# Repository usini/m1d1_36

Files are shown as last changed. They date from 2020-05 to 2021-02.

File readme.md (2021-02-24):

µsini M1D1_36
-------------
An Open Source Midi controller with **36 pads** in a **compact body**.

Documentation en français : https://usini.github.io/m1d1_36/index.html

Make music on a PC or with open source sound modules.
* 36 capacitives pads  
* 4 Potentiometers    
* 10 buttons    

Based Sparkfun Pro Micro (atmega32u4)
https://www.sparkfun.com/products/12640

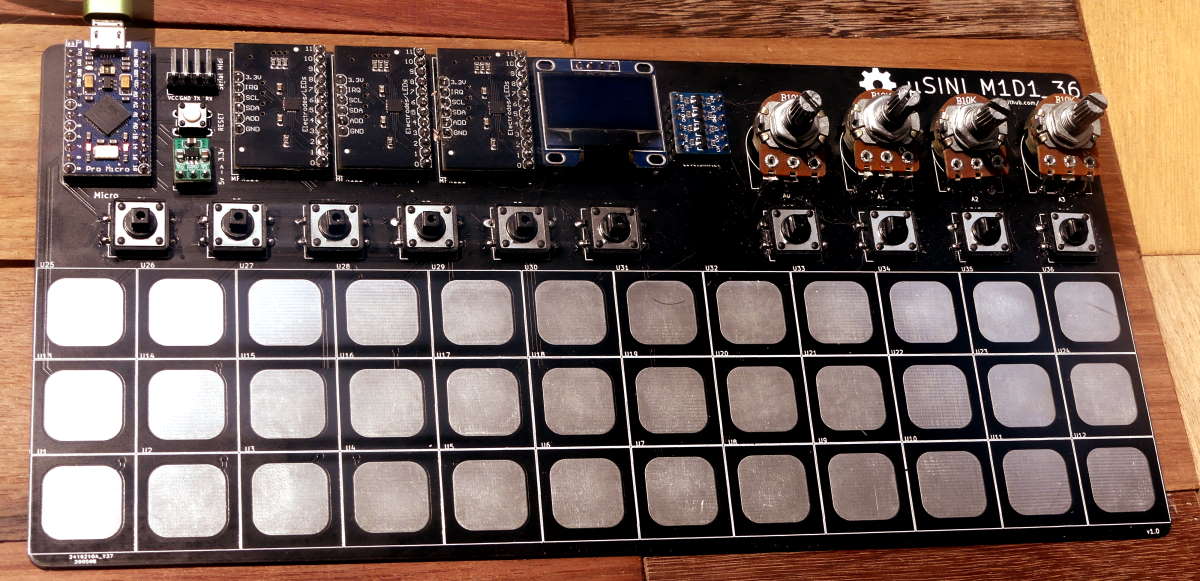
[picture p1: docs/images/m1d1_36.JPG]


# Demo

# USB Midi
Compatible with any music software   
Can also be used as a keyboard / mouse / xbox360 controller...

## Examples
LMMS - Open Source Music Software - https://lmms.io/download#windows   
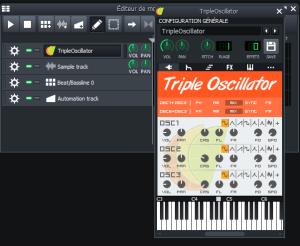
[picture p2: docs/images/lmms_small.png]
LMMS
   

PatchBox OS - Raspberry Pi synthetiser - https://blokas.io/modep/
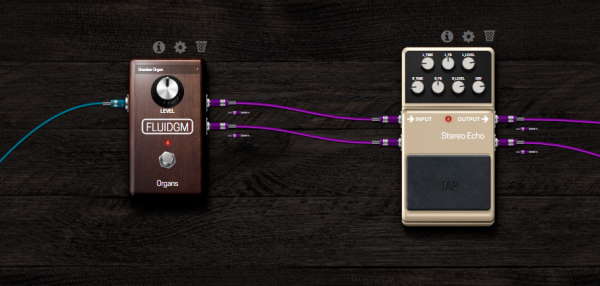
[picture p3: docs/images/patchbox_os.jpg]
PatchBox OS
 

# Serial Midi
Add controls / sound generators using open sources modules
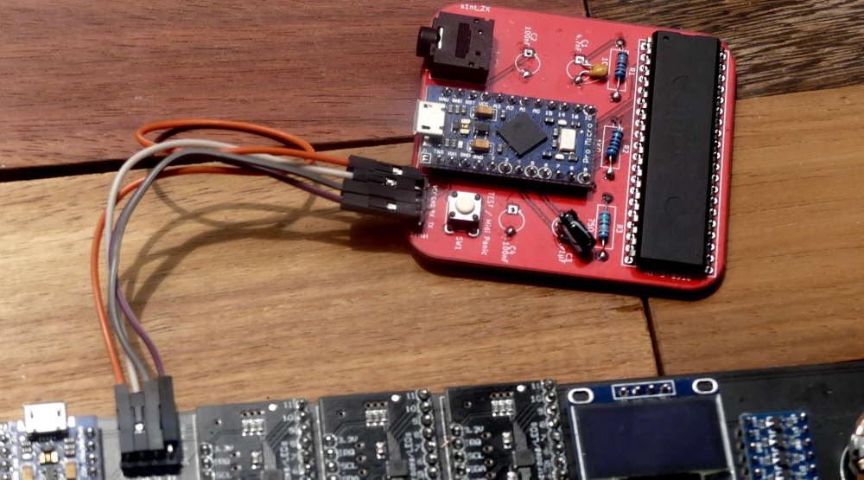
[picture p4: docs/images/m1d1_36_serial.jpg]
     
    
## Compatibles Modules
* **µsini zx** [TO BE PUBLISHED] : a AY-3-8910 sound generator (used in zx-spectrum)   
 Based on Ian Harvey design (public domain) : https://www.instructables.com/id/Arduino-MIDI-Chiptune-Synthesizer/

* **µsini opl2** [WAITING FOR COMPONENTS] : A OPL-2 FM sound generator (used in adlib sound card)   
  Based on Maarten Janssen design (MIT licence) : https://hackaday.io/project/18995-opl2-audio-board-for-arduino-raspberry-pi

* **µsini M1d1 Out** [TO MAKE] : A serial pins to Midi output
* **µsini M1d1 WiFi** [TO MAKE] : A serial midi to RtpMidi (WiFi Midi)
* **µsini M1d1 BLE** [TO MAKE] : A serial midi to BLE 

# Make your own
Fast and easy to solder as this midi controller used only modules.

## Send Gerbers to PCB Manufacturer

## Buy component
You can either choose to buy components from a chinese clone manufacturer or the original source.

### Clone links (sponsored)

### Sparkfun links

## Solder it

## Upload code

# Easy to customize code
Easy to use events system

Each times a pad / buttons is pressed or a potentiometers is moved, theses functions are triggered: 
* potsEvent()
* buttonsEvent()
* MPREvent()

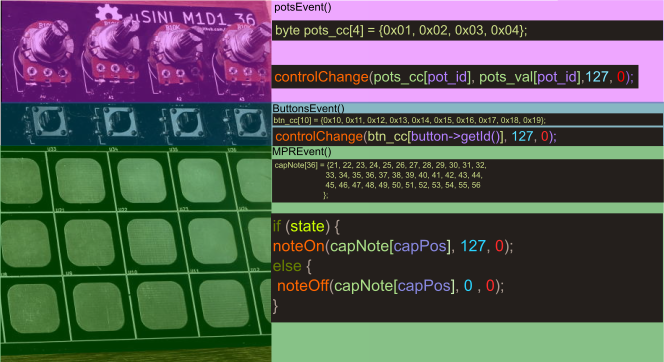
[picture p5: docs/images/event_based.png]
m1d1_36 Event based system
  

Developer documentation : LINK

# Easy to customize schematics

noob friendly schematics for Kicad.  
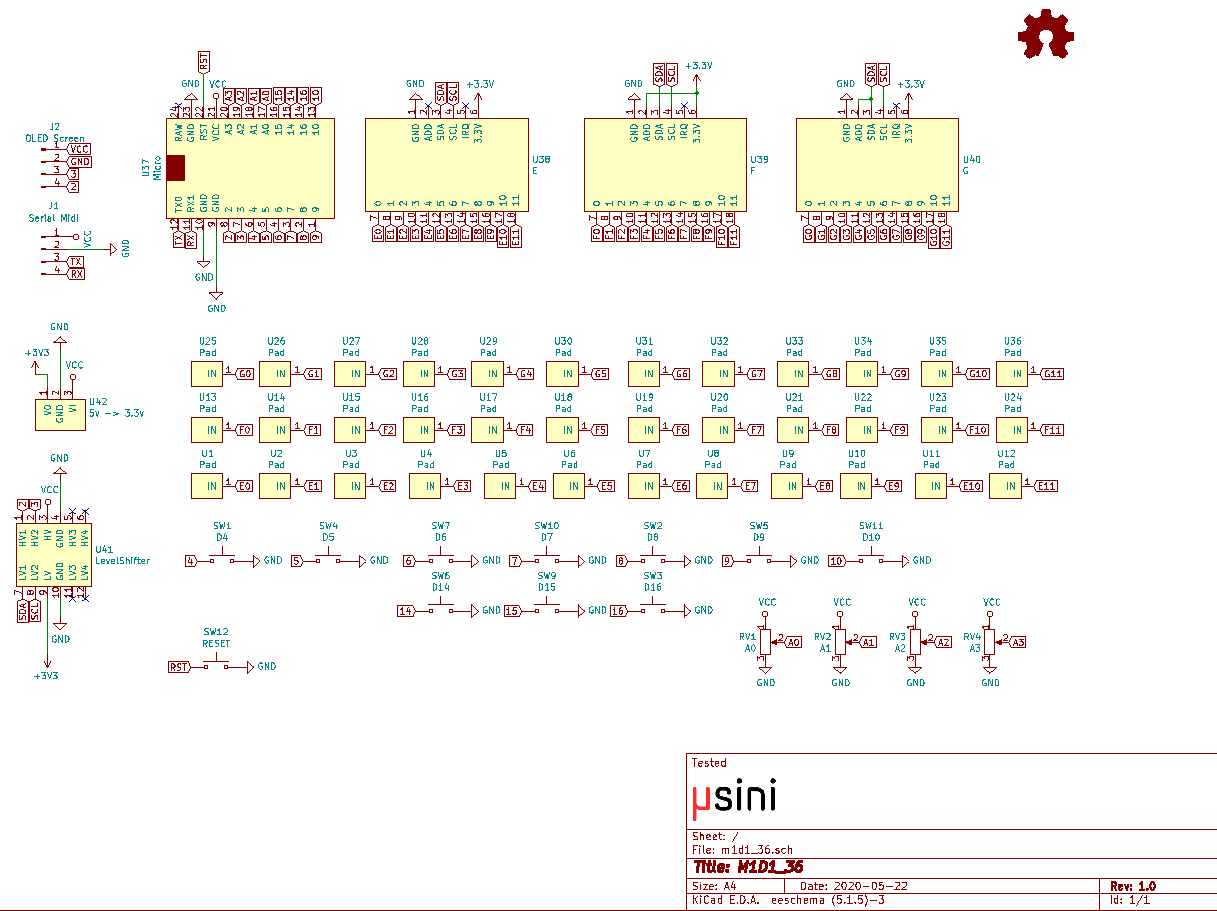
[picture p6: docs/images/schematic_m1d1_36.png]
m1d1_36 Schematics
  

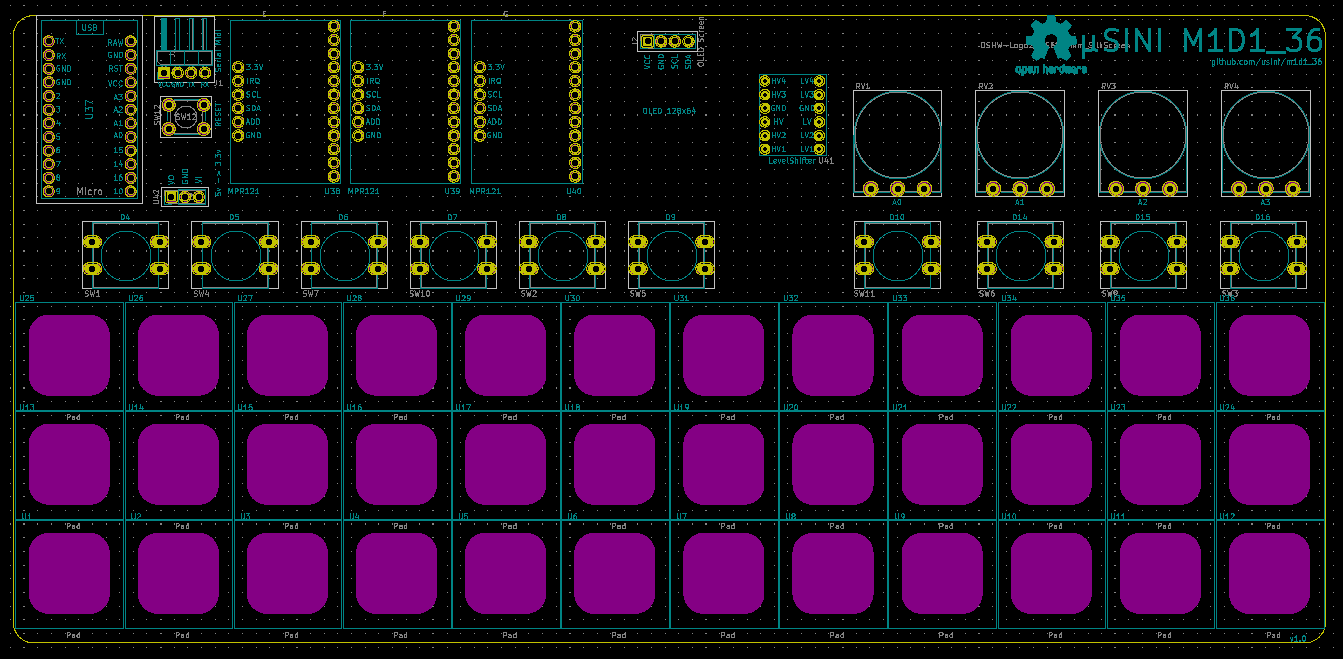
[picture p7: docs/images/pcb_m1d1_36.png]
PCB
  

## 3D models
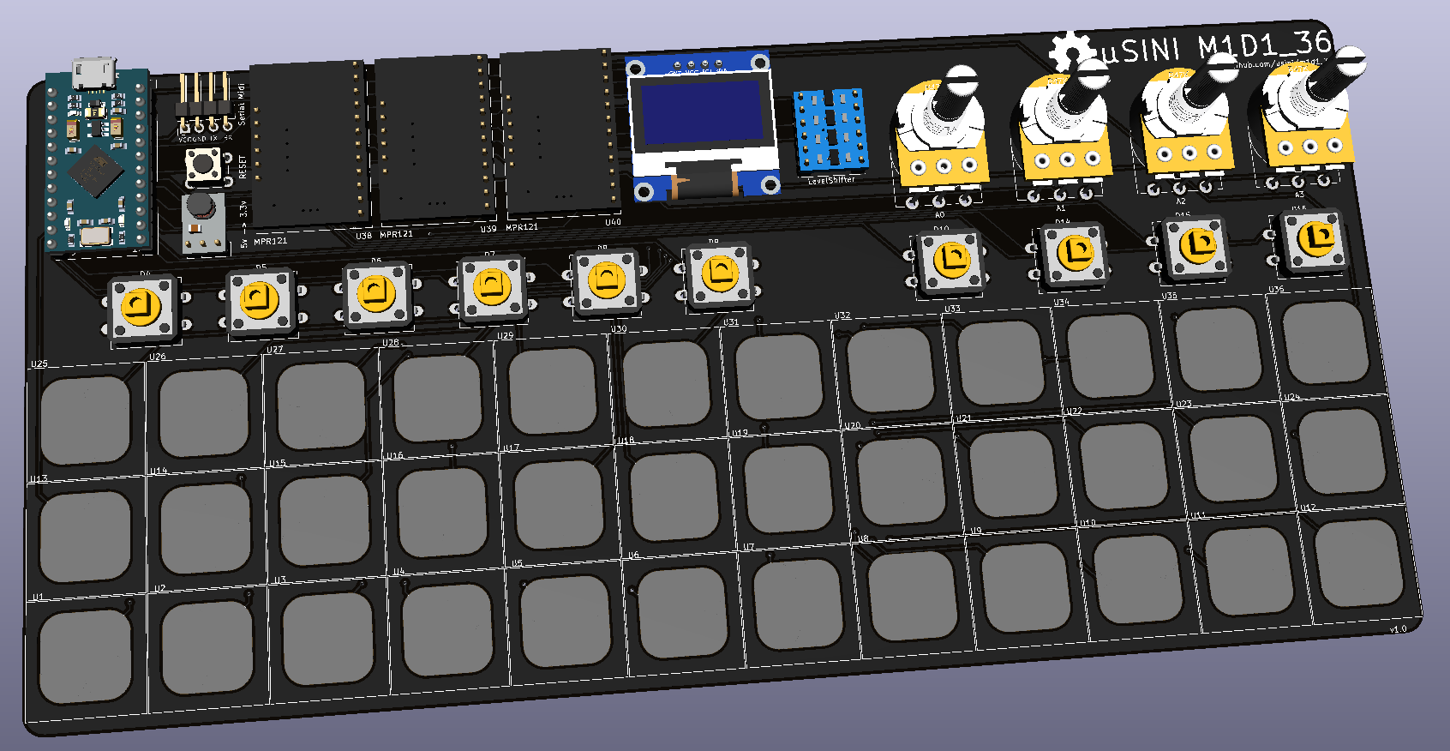
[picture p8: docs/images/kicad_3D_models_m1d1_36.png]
m1d1_36 3D Models
 

* pro_micro.step - **Andrew_Witham** - https://grabcad.com/library/arduino-pro-micro-1
* stepdown.STEP - **Hasanain Shuja**   - https://grabcad.com/library/   dd0503ma-ultra-mini-dc-3-7v-4-5v-5v-to-3-3v-dc-dc-step-down-converter-buck-module-2    
* oled.step - **CDMX ELECTRONICA** - https://grabcad.com/library/display-oled-ssd1306-de-0-96-1     
* mpr121.step - **SPARKFUN** - https://www.sparkfun.com/products/retired/9695     
* logic_level.step - **SPARKFUN** - https://www.sparkfun.com/products/12009     
* 12mmx12mm Without cap.step - **Nilton** - https://grabcad.com/library/    
* 12mm-button-without-cap-with-round-square-cap-1
pot.step - **Mirko Ragni** - https://grabcad.com/library/47k-potentiometer-1   

# Open source as its core
## Make your own midi controller and sell it.   
Documentations / Codes and components, everything is licenced so you can make your own controller and sell it.

## Open source modules
Except for the OLED screen / 5v to 3.3v voltage regulator, all modules are licenced Creative Commons Share-alike 3.0 by Sparkfun.   

Eagles Files
* Pro Micro - http://cdn.sparkfun.com/datasheets/Dev/Arduino/Boards/SparkFun_Pro_Micro_v13a.zip

* MPR121 - http://cdn.sparkfun.com/datasheets/BreakoutBoards/MPR121-Breakout-v13.zip

* Logic Level Converter - http://cdn.sparkfun.com/datasheets/BreakoutBoards/Logic_Level_Bidirectional.zip

## Open Source code

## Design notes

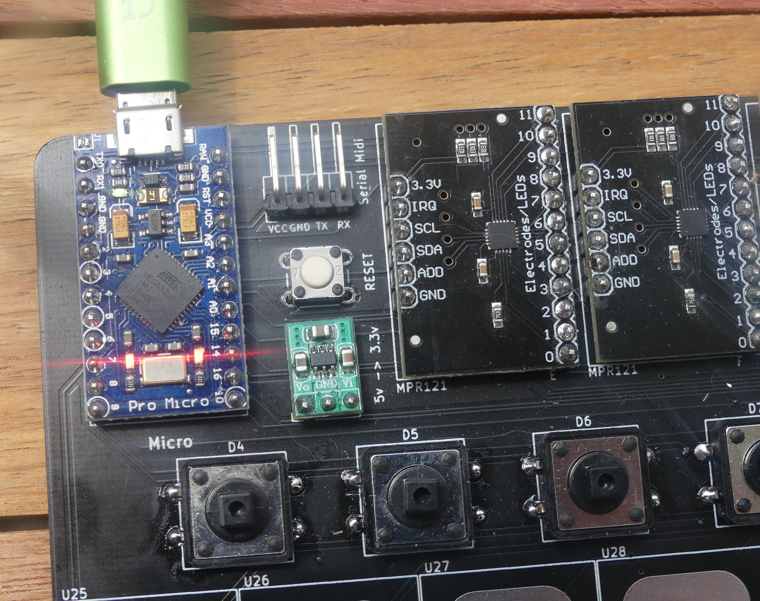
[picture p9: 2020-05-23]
docs/images/m1d1_36_pro_micro.jpg

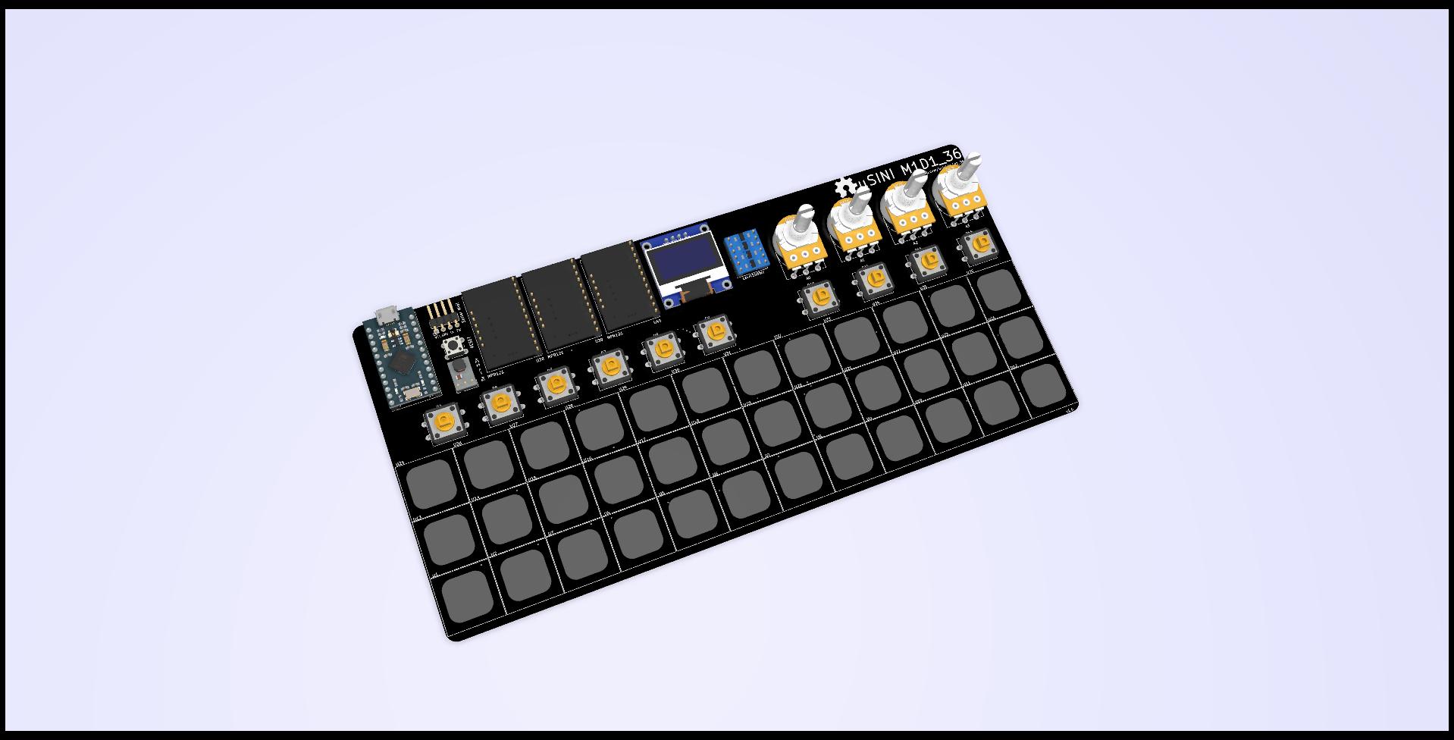
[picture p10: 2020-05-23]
kicad/m1d1_36/render/m1d1_36.jpg

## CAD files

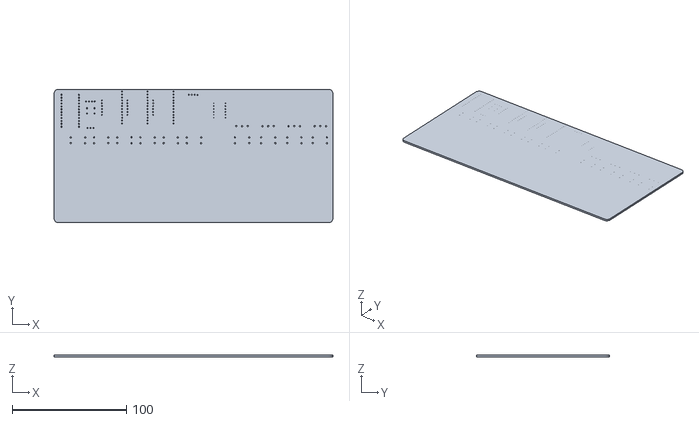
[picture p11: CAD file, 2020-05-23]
kicad/m1d1_36/render/pcb.obj
244.3 x 116.8 x 1.60

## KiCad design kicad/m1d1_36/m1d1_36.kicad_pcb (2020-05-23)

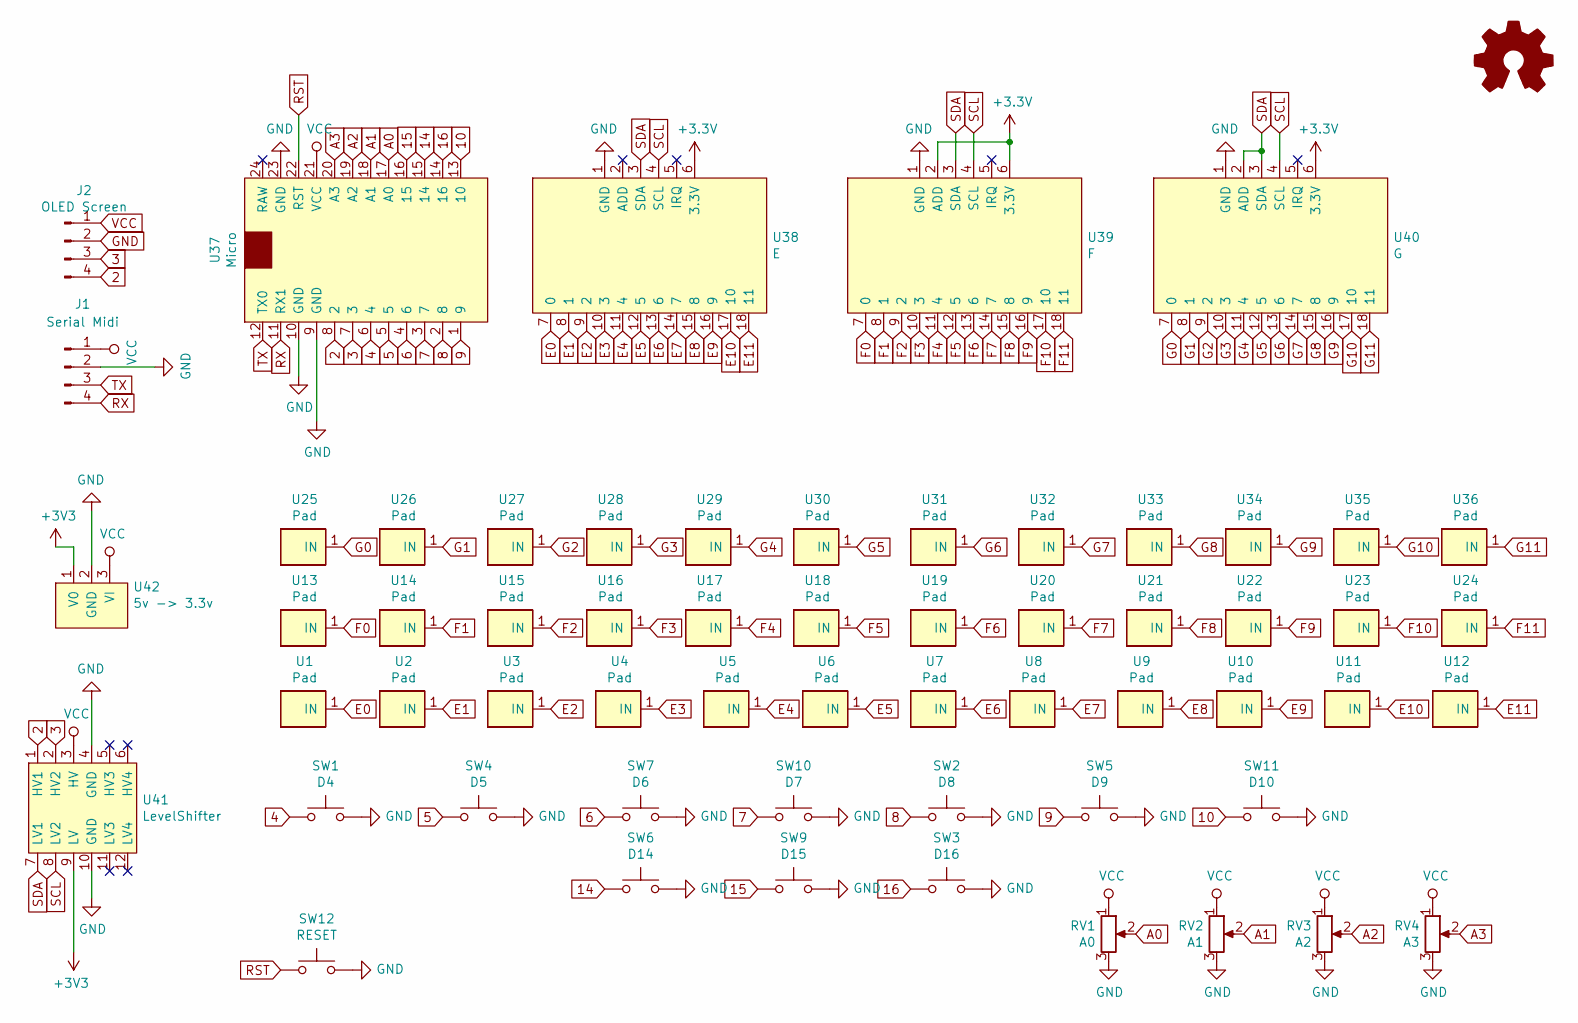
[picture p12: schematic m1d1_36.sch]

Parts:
J1: Serial Midi; PinHeader_1x04_P2.54mm_Horizontal
J2: OLED Screen; oled_128x64
RV1: A0; pot
RV2: A1; pot
RV3: A2; pot
RV4: A3; pot
SW1: D4; SW_PUSH-12mm
SW2: D8; SW_PUSH-12mm
SW3: D16; SW_PUSH-12mm
SW4: D5; SW_PUSH-12mm
SW5: D9; SW_PUSH-12mm
SW6: D14; SW_PUSH-12mm
SW7: D6; SW_PUSH-12mm
SW9: D15; SW_PUSH-12mm
SW10: D7; SW_PUSH-12mm
SW11: D10; SW_PUSH-12mm
SW12: RESET; SW_PUSH_6mm
U1, U2, U3, U4, U5, U6, U7, U8, U9, U10, U11, U12, U13, U14, U15, U16, U17, U18, U19, U20, U21, U22, U23, U24, U25, U26, U27, U28, U29, U30, U31, U32, U33, U34, U35, U36: Pad; pad
U37: Micro; pro_micro
U38: E; mpr121
U39: F; mpr121
U40: G; mpr121
U41: LevelShifter
U42: 5v -> 3.3v; voltage_regulator

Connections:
2: J2.4, U37.8 (2), U41.1 (HV1)
3: J2.3, U37.7 (3), U41.2 (HV2)
4: SW1.1, U37.6 (4)
5: SW4.1, U37.5
6: SW7.1, U37.4 (6)
7: SW10.1, U37.3 (7)
8: SW2.1, U37.2 (8)
9: SW5.1, U37.1 (9)
10: SW11.1, U37.13 (10)
14: SW6.1, U37.15 (14)
15: SW9.1, U37.16 (15)
16: SW3.1, U37.14 (16)
A0: RV1.2, U37.17 (A0)
A1: RV2.2, U37.18 (A1)
A2: RV3.2, U37.19 (A2)
A3: RV4.2, U37.20 (A3)
E0: U1.1, U38.7 (0)
E1: U2.1, U38.8 (1)
E2: U3.1, U38.9 (2)
E3: U4.1, U38.10 (3)
E4: U5.1, U38.11 (4)
E5: U6.1, U38.12 (5)
E6: U7.1, U38.13 (6)
E7: U8.1, U38.14 (7)
E8: U9.1, U38.15 (8)
E9: U10.1, U38.16 (9)
E10: U11.1, U38.17 (10)
E11: U12.1, U38.18 (11)
F0: U13.1, U39.7 (0)
F1: U14.1, U39.8 (1)
F2: U15.1, U39.9 (2)
F3: U16.1, U39.10 (3)
F4: U17.1, U39.11 (4)
F5: U18.1, U39.12 (5)
F6: U19.1, U39.13 (6)
F7: U20.1, U39.14 (7)
F8: U21.1, U39.15 (8)
F9: U22.1, U39.16 (9)
F10: U23.1, U39.17 (10)
F11: U24.1, U39.18 (11)
G0: U25.1, U40.7 (0)
G1: U26.1, U40.8 (1)
G2: U27.1, U40.9 (2)
G3: U28.1, U40.10 (3)
G4: U29.1, U40.11 (4)
G5: U30.1, U40.12 (5)
G6: U31.1, U40.13 (6)
G7: U32.1, U40.14 (7)
G8: U33.1, U40.15 (8)
G9: U34.1, U40.16 (9)
G10: U35.1, U40.17 (10)
G11: U36.1, U40.18 (11)
GND: J1.2, J2.2, RV1.3, RV2.3, RV3.3, RV4.3, SW1.2, SW2.2, SW3.2, SW4.2, SW5.2, SW6.2, SW7.2, SW9.2, SW10.2, SW11.2, SW12.2, U37.9 (GND), U37.10 (GND), U37.23 (GND), U38.1 (GND), U39.1 (GND), U40.1 (GND), U41.4 (GND), U41.10 (GND), U42.2 (GND)
RST: SW12.1, U37.22 (RST)
RX: J1.4, U37.11 (RX1)
SCL: U38.4 (SCL), U39.4 (SCL), U40.4 (SCL), U41.8 (LV2)
SDA: U38.3 (SDA), U39.3 (SDA), U40.2 (ADD), U40.3 (SDA), U41.7 (LV1)
TX: J1.3, U37.12 (TX0)
VCC: J1.1, J2.1, RV1.1, RV2.1, RV3.1, RV4.1, U37.21 (VCC), U41.3 (HV), U42.3 (VI)

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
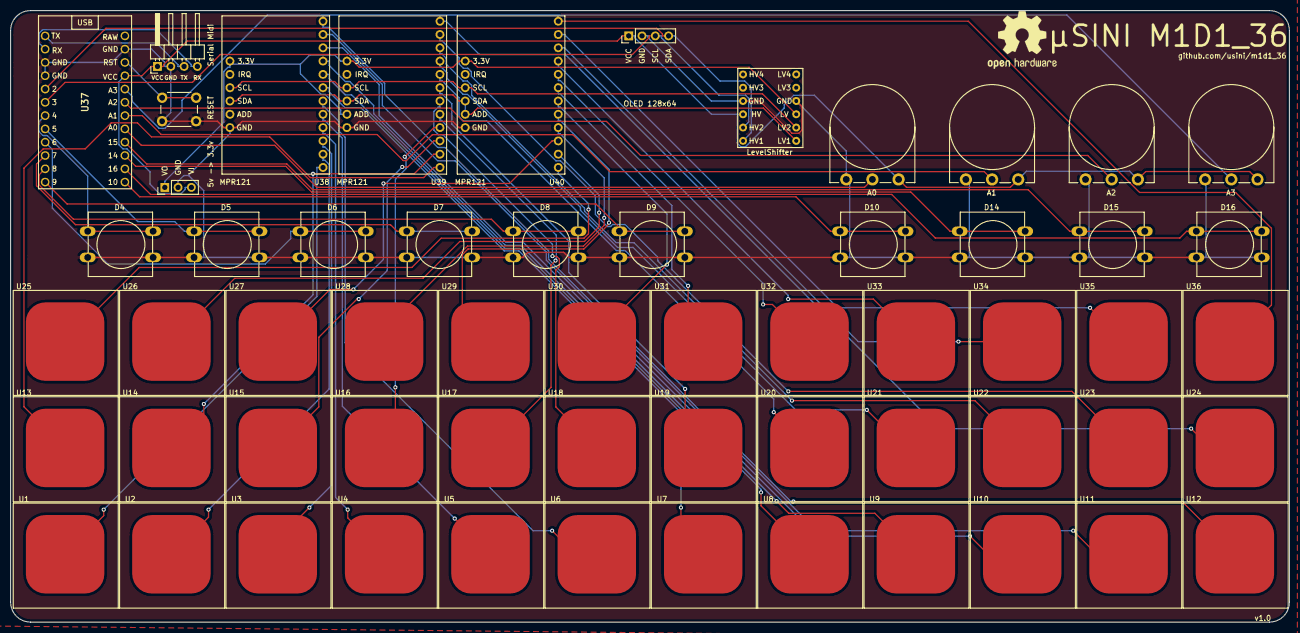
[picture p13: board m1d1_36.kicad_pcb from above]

Board: 2 copper layers, 244.3 x 116.8 mm, 59 parts (0 on the bottom side), 60 nets.

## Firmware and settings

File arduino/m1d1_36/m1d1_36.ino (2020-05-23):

/*! 
 * @file m1d1_36.ino
 * 
 * @mainpage µsini M1D1_36 v1.0: A 36 Capacitive Pad Midi Controller
 * 
 * @section intro_sec Introduction
 *
 * µsini M1D1_36 v1.0: A 36 Capacitive Pad Midi Controller \n
 * For more informations go to https://github.com/usini/midi_36
 *
 * @section dependencies Dependencies
 * AceButton        : https://github.com/bxparks/AceButton \n
 * MIDIUSB          : https://www.arduino.cc/en/Reference/MIDIUSB \n
 * Adafruit SSD1306 : https://github.com/adafruit/Adafruit_SSD1306 \n
 * Adafruit MPR121  : https://github.com/adafruit/Adafruit_MPR121 \n 
 * 
 * @section author Author
 * 
 * Written by Rémi Sarrailh for µsini, with 
 * contributions from the open source community
 * 
 * @section licence Licence
 * 
 * MIT Licence
*/

// Libraries
#include <Wire.h>
#include <Adafruit_GFX.h>
#include <Adafruit_SSD1306.h>
#include <AceButton.h>
#include "Adafruit_MPR121.h"
#include "MIDIUSB.h"

// Internal code
#include "settings.h" //Settings
#include "midi.h"
#include "buttons.h" //Buttons
#include "pots.h" //Potentiometers
#include "mpr121.h" // Pads
#include "OLED.h" //Display (OLED)

/*!
 *  @brief Settings all components
*/
void setup() {
  if (SERIAL_ACTIVE) {
    Serial.println("M1D1_36 Startup");
  }

  setupMIDI();
  setupMPR();
  setupButtons();
  setupOLED();
}

/*!
 *  @brief Check all components and generate events
*/
void loop() {
  // To test the buttons / Potentiometers, disable all code but testButtons(); or testPots();
  // testButtons();
  // testPots();

  checkMPR(capE.touched(), 0);
  checkMPR(capF.touched(), 1);
  checkMPR(capG.touched(), 2);
  checkPots();
  checkButtons();
  checkOLED(); //Check if OLED need to be refresh
  MidiUSB.flush();
}

/*!
 *  @brief When a pad is pressed / released
 * 
 *  @param capPos
 *        Pad position (from 0 to 36)
 *  @param note
 *        Notes in capNote (see settings.h)
 *  @param state
 *        Is the pad currently pressed or released
 *  @param mpr_id
 *        Which MPR121 module is used (from 0 to 2)
 *  @param cap_id
 *        Which pad is used on the MPR121 (from 0 to 11)
*/
void MPREvent(int capPos, int note, bool state, int mpr_id, int cap_id) {
  if (state) {
    // NoteON (with transposition)
    noteOn(note + (12 * transpose), 127, channel);
    // Draw pad position on OLED
    drawMPR(mpr_id, cap_id, true);
    // Display Pad pressed on Serial
    serialMPR(capPos, note, true);
  } else {
    // NoteOFF (with transposition)
    noteOff(note + (12 * transpose), 0, channel);
    // Draw pad position on OLED
    drawMPR(mpr_id, cap_id, false);
    // Display Pad release on Serial
    serialMPR(capPos, note, false);
  }
}

/*!
 *  @brief When a potentiometer is used
 * 
 *  @param pot_id
 *        Potentiometer id (from 0 to 3)
*/
void potsEvent(int pot_id) {
  controlChange(pots_cc[pot_id], pots_val[pot_id], channel);
  drawPots();
  serialPots(pot_id, pots_val[pot_id]);
}

/*!
 *  @brief When a button is pressed / released
 * 
 *  @param button
 *        Acebutton object (button->getId() to get ID)
 *  @param eventType
 *        Is the button press / release / double click / long press / repeatly press
 *  @param buttonState 
 *        Is the button was pressed or released
*/
void buttonsEvent(AceButton* button, uint8_t eventType, uint8_t buttonState) {
  uint8_t id = button->getId();
  switch (eventType) {
    //Button is pressed
    case AceButton::kEventPressed:
      //Change buttons state (toggle mode)
      if (id < 6) { // First 6 buttons are used as midi

        btn[id] = !btn[id]; //Invert button state
        //Button ON = 127 / Button OFF = 0
        uint8_t val = 0;
        if (btn[id]) {
          val = 127;
        }

        controlChange(btn_cc[id], val, channel); //Send CC command (cc, value, channel)
        drawButtons(id, btn[id]);
        serialButtons(id, val);
      } else {
        switch (id) { //Last buttons are use to change Channel / Transpose
          case 6:
            if (transpose != 0) {
              transpose--;
              drawTranspose();
            }
            break;
          case 7:
            if (transpose <= 6) {
              transpose++;
              drawTranspose();
            }
            break;
          case 8:
            if (channel != 1) {
              channel--;
              drawChannel();
            }
            break;
          case 9:
            if (channel < 16) {
              channel++;
              drawChannel();
            }
            break;
        }
      }
      break;

      /*
        case AceButton::kEventReleased:
        break;

        case AceButton::kEventDoubleClicked:
        break;

        case AceButton::kEventLongPressed:
        break;

        case AceButton::kEventRepeatPressed:
        break;
      */
  }
}

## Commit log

2020-05-23 Dump v1.0
    [m1d1_36-B_Cu.gbr, m1d1_36-B_Mask.gbr, m1d1_36-B_Paste.gbr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]
2024-07-29 Add platformio project (just capacitive no buttons/pots)
